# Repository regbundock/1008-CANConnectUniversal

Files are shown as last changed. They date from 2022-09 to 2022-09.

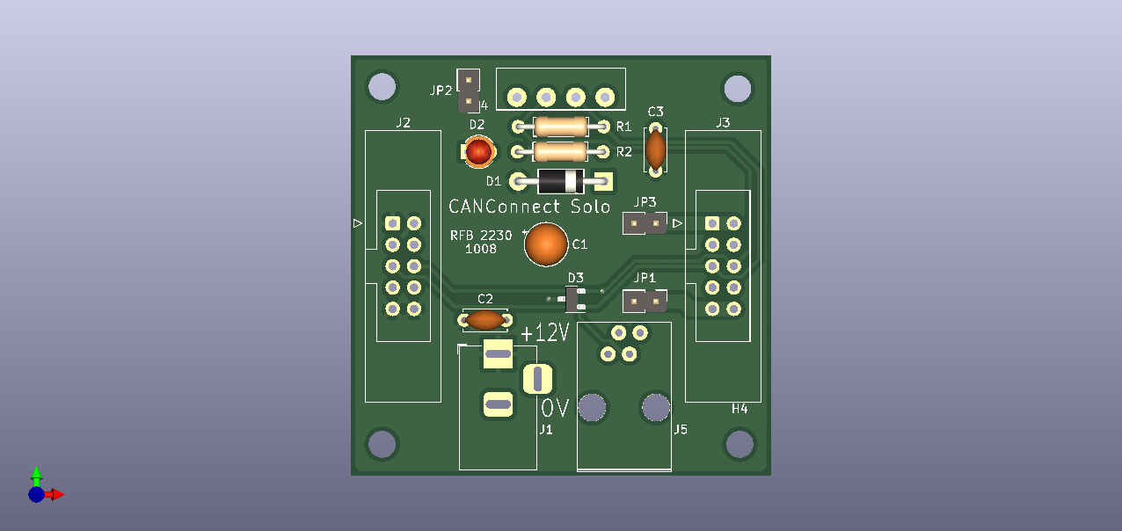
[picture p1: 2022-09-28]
1008-CANConnectUniversal.png

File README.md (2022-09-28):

1009-CANConnectUniversal

This board is multi-functional. It connects the CBUS module or modules to
the ribbon cable, it accepts power from a 12V suupply, allows the +12V
power line to be broken to provide an isolated power zone ang provides an
interface for a CANCAB.

It provides all that is necessary to run a small CBUS system for testing.
A CANUSB4 is also needed to allow the FCU or JMRI to be used.

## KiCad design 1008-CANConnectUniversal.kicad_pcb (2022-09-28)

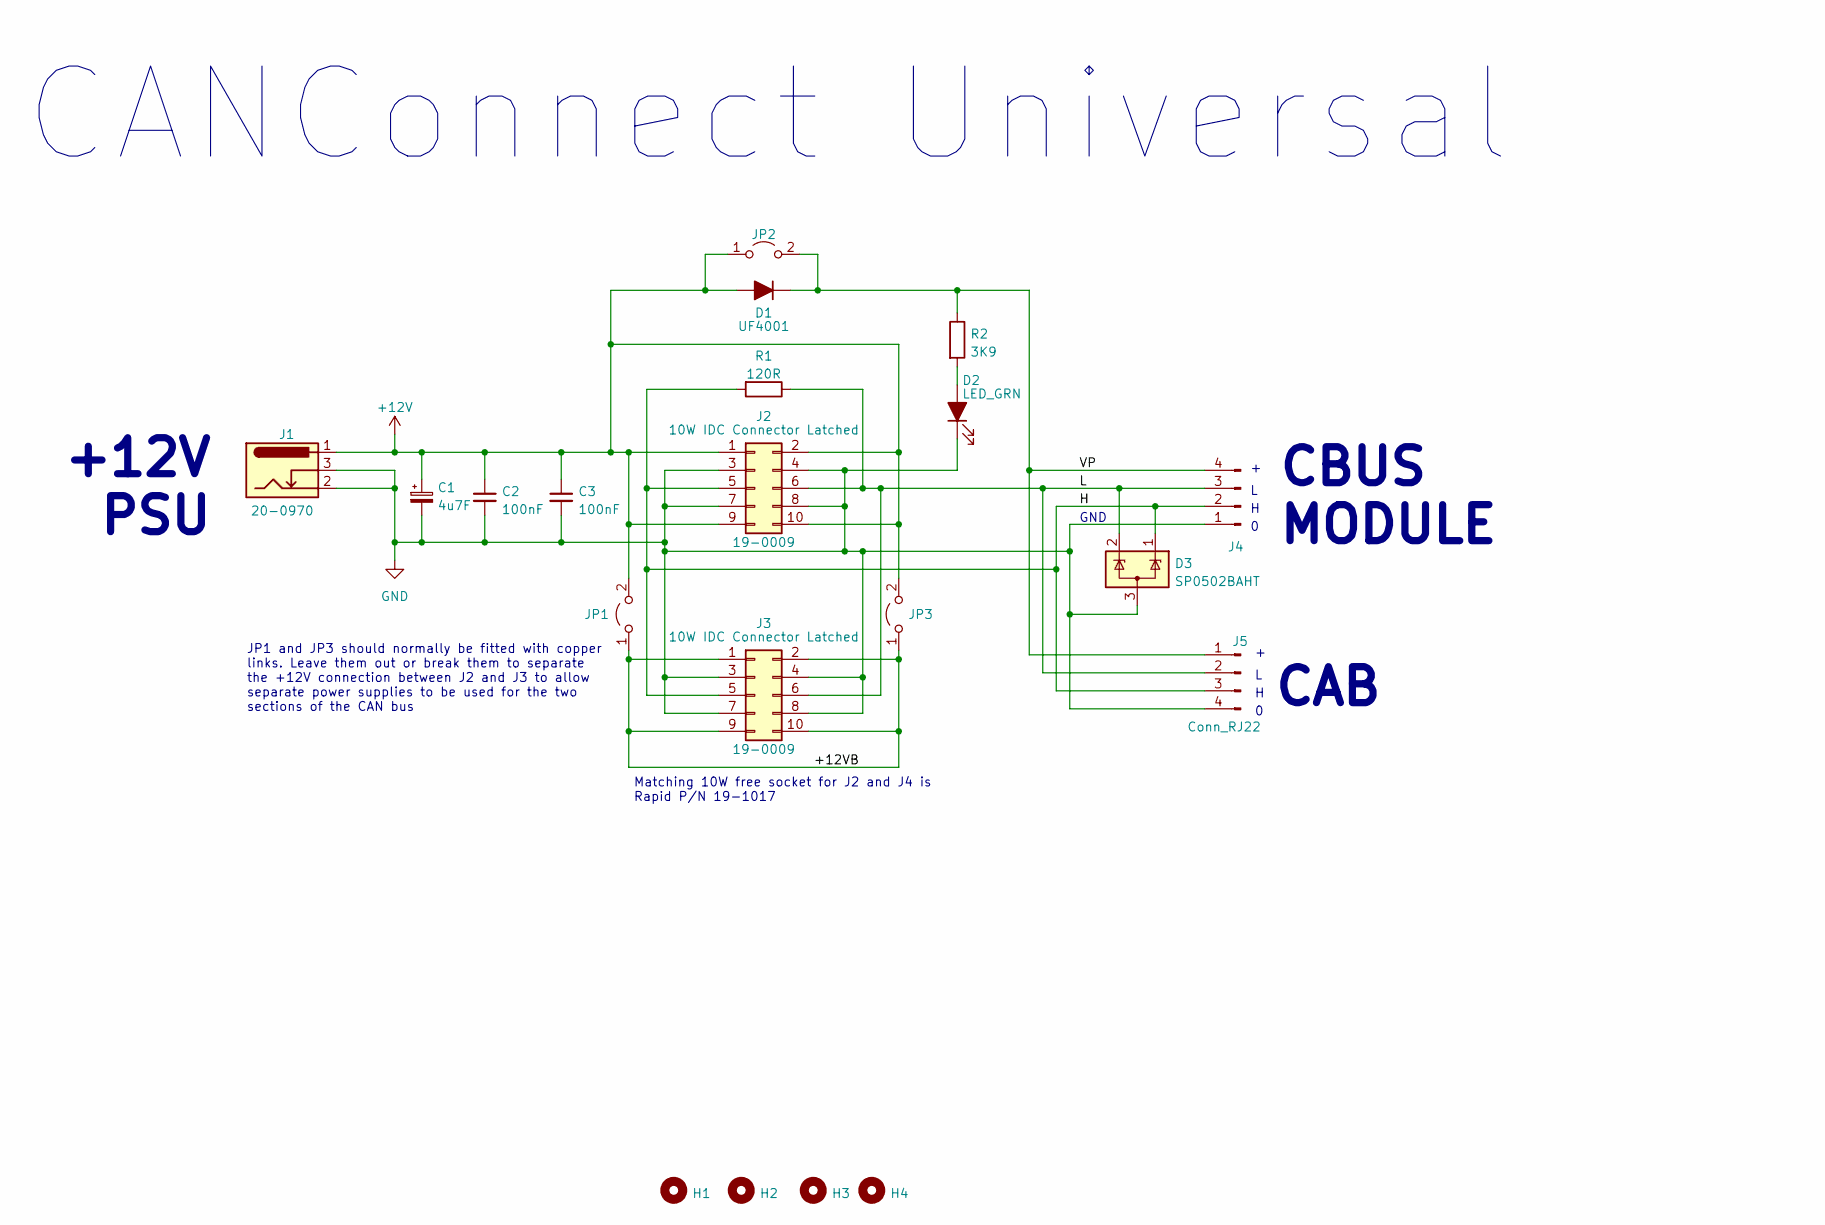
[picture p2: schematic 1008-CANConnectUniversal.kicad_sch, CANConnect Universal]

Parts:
C1: 4u7F; CP_Radial_Tantal_D5.0mm_P2.50mm
C2, C3: 100nF; C_Disc_D5.0mm_W2.5mm_P5.00mm
D1: UF4001; D_DO-41_SOD81_P10.16mm_Horizontal
D2: LED_GRN; LED_D3.0mm
D3: SP0502BAHT; SOT-23
H1, H2, H3, H4: MountingHole; MountingHole_3.2mm_M3
J1: 2.1mm PCB Power Socket; BarrelJack_Horizontal; Part no. 20-0970
J2, J3: 10W IDC Connector Latched; IDC-Header_2x05_P2.54mm_Latch_Vertical; Part No. 19-0009
J4: Conn_01x04_Male; Camdenboss_3pt5mm_pitch_PCB_horizontal_4Way
J5: Conn_RJ22; RJ22
JP1, JP2, JP3: Jumper_2_Open; PinHeader_1x02_P2.54mm_Vertical
R1: 120R; R_Axial_P10.16mm_Horizontal
R2: 3K9; R_Axial_P10.16mm_Horizontal

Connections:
+12V: C1.1, C2.1, C3.1, D1.2 (A), J1.1, J2.1, J2.2, J2.9, J2.10, JP1.2 (B), JP2.1 (A), JP3.2 (B)
/+12VB: J3.1, J3.2, J3.9, J3.10, JP1.1 (A), JP3.1 (A)
/H: D3.1 (K), J2.5, J3.5, J4.2, J5.3, R1.2
/L: D3.2 (K), J2.6, J3.6, J4.3, J5.2, R1.1
/VP: D1.1 (K), J4.4, J5.1, JP2.2 (B), R2.1
GND: C1.2, C2.2, C3.2, D2.1 (K), D3.3 (A), J1.2, J1.3, J2.3, J2.4, J2.7, J2.8, J3.3, J3.4, J3.7, J3.8, J4.1, J5.4
unnamed: D2.2 (A), R2.2

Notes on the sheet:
CANConnect Universal
JP1 and JP3 should normally be fitted with copper links. Leave them out or break them to separate the +12V connection between J2 and J3 to allow separate power supplies to be used for the two sections of the CAN bus
CAB
+12V PSU
GND
CBUS MODULE
Matching 10W free socket for J2 and J4 is Rapid P/N 19-1017

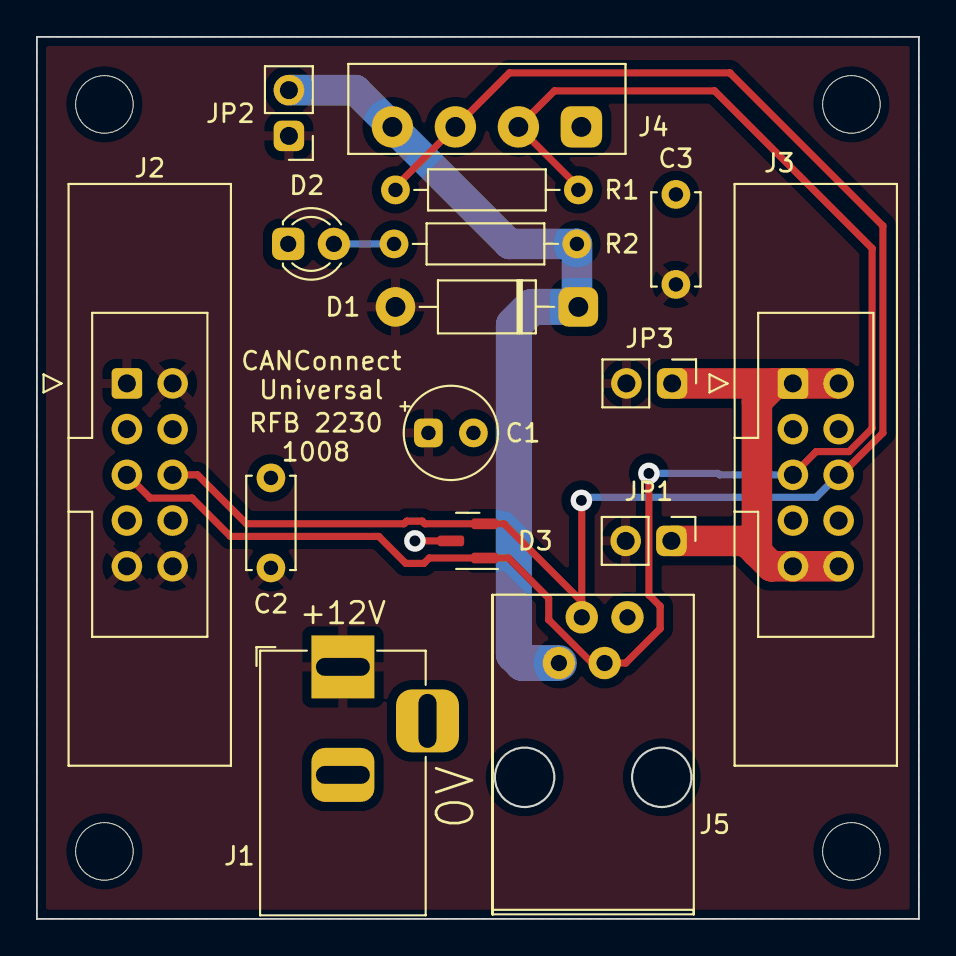
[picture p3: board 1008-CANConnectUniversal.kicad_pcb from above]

Board: 2 copper layers, 49.0 x 49.0 mm, 20 parts (0 on the bottom side), 7 nets.
